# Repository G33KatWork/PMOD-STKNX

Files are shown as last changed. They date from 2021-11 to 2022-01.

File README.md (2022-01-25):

STKNX Pmod
==========

**WARNING**: See [known issues](#known-issues) before ordering boards!

This is a small breakout board for an ST microelectronics [STKNX KNX line transceiver](https://www.st.com/en/interfaces-and-transceivers/stknx.html)

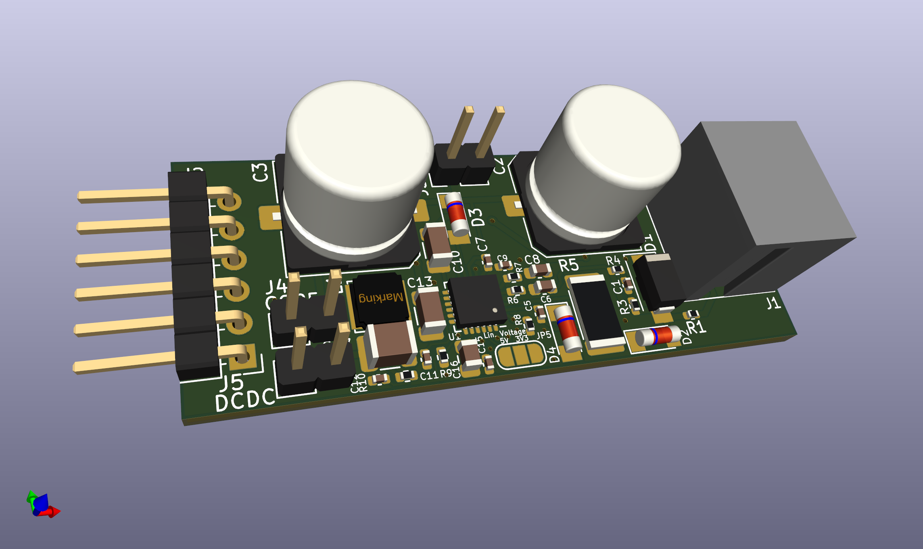
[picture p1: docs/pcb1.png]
PCB Front


Hardware
--------

The board is currently being manufactured and the design has briefly been powered up and tested - it didn't go up in flames... yet. It is very close to the ST reference design of the EVALKITSTKNX development board, just without the microcontroller

The STKNX is not a full KNX MAC. It is only a line transceiver that performs some KNX bus compliant signal conditioning and also delivers power using its voltage regulators from the bus to the device.

There is no real open source software support right now for bit-banging the KNX protocol using this transceiver. It is very useful to perform sniffing tasks on the bus if you are interested in the raw bits that are sent.

Known issues
------------

The polarization of the KNX connector is wrong. It's a pretty dumb mistake, but oh well, it happened.

Possible solutions:

1. Don't care, connect the red wire to the black terminal and vice versa
2. Don't care like in 1) but use the yellow/white WAGO terminal to make sure you remember to swap the polarity
3. Take apart a WAGO terminal by force and swap the black and red terminal
4. Solder the pins on the bottom of the board and plug the WAGO terminal in there.
5. Cut the GND connections on the one pin, cut the bus connection on the other pin and bodge the GND and bus connection to the right pins
6. Fix it in the board design, reorder and rebuild the boards

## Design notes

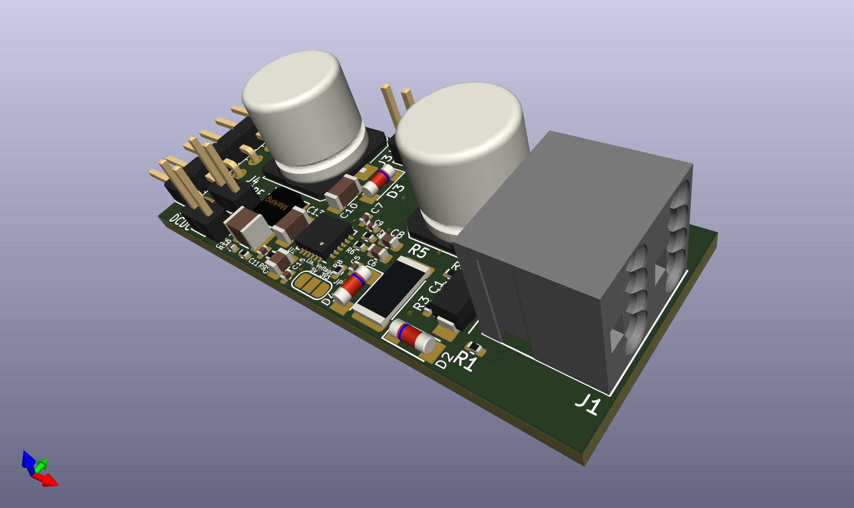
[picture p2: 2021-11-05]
docs/pcb3.png

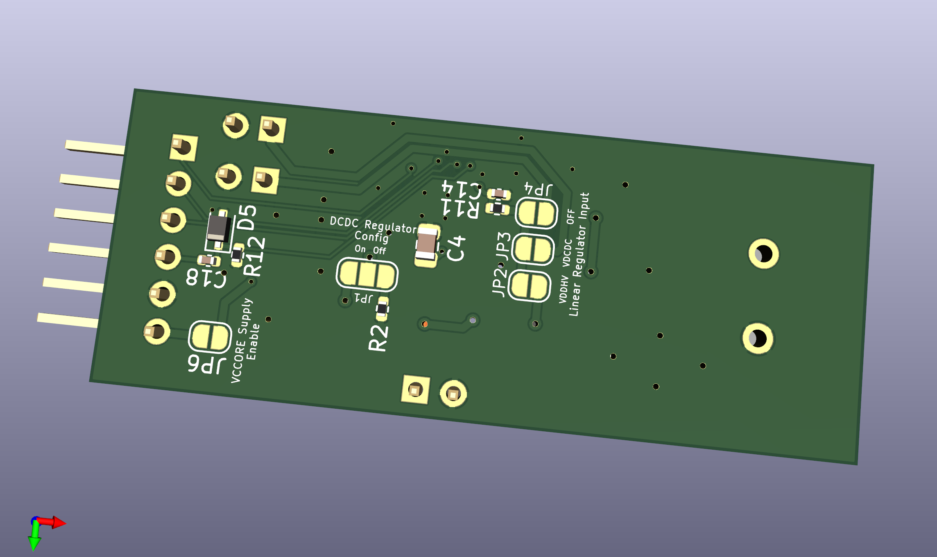
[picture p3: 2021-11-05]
docs/pcb2.png

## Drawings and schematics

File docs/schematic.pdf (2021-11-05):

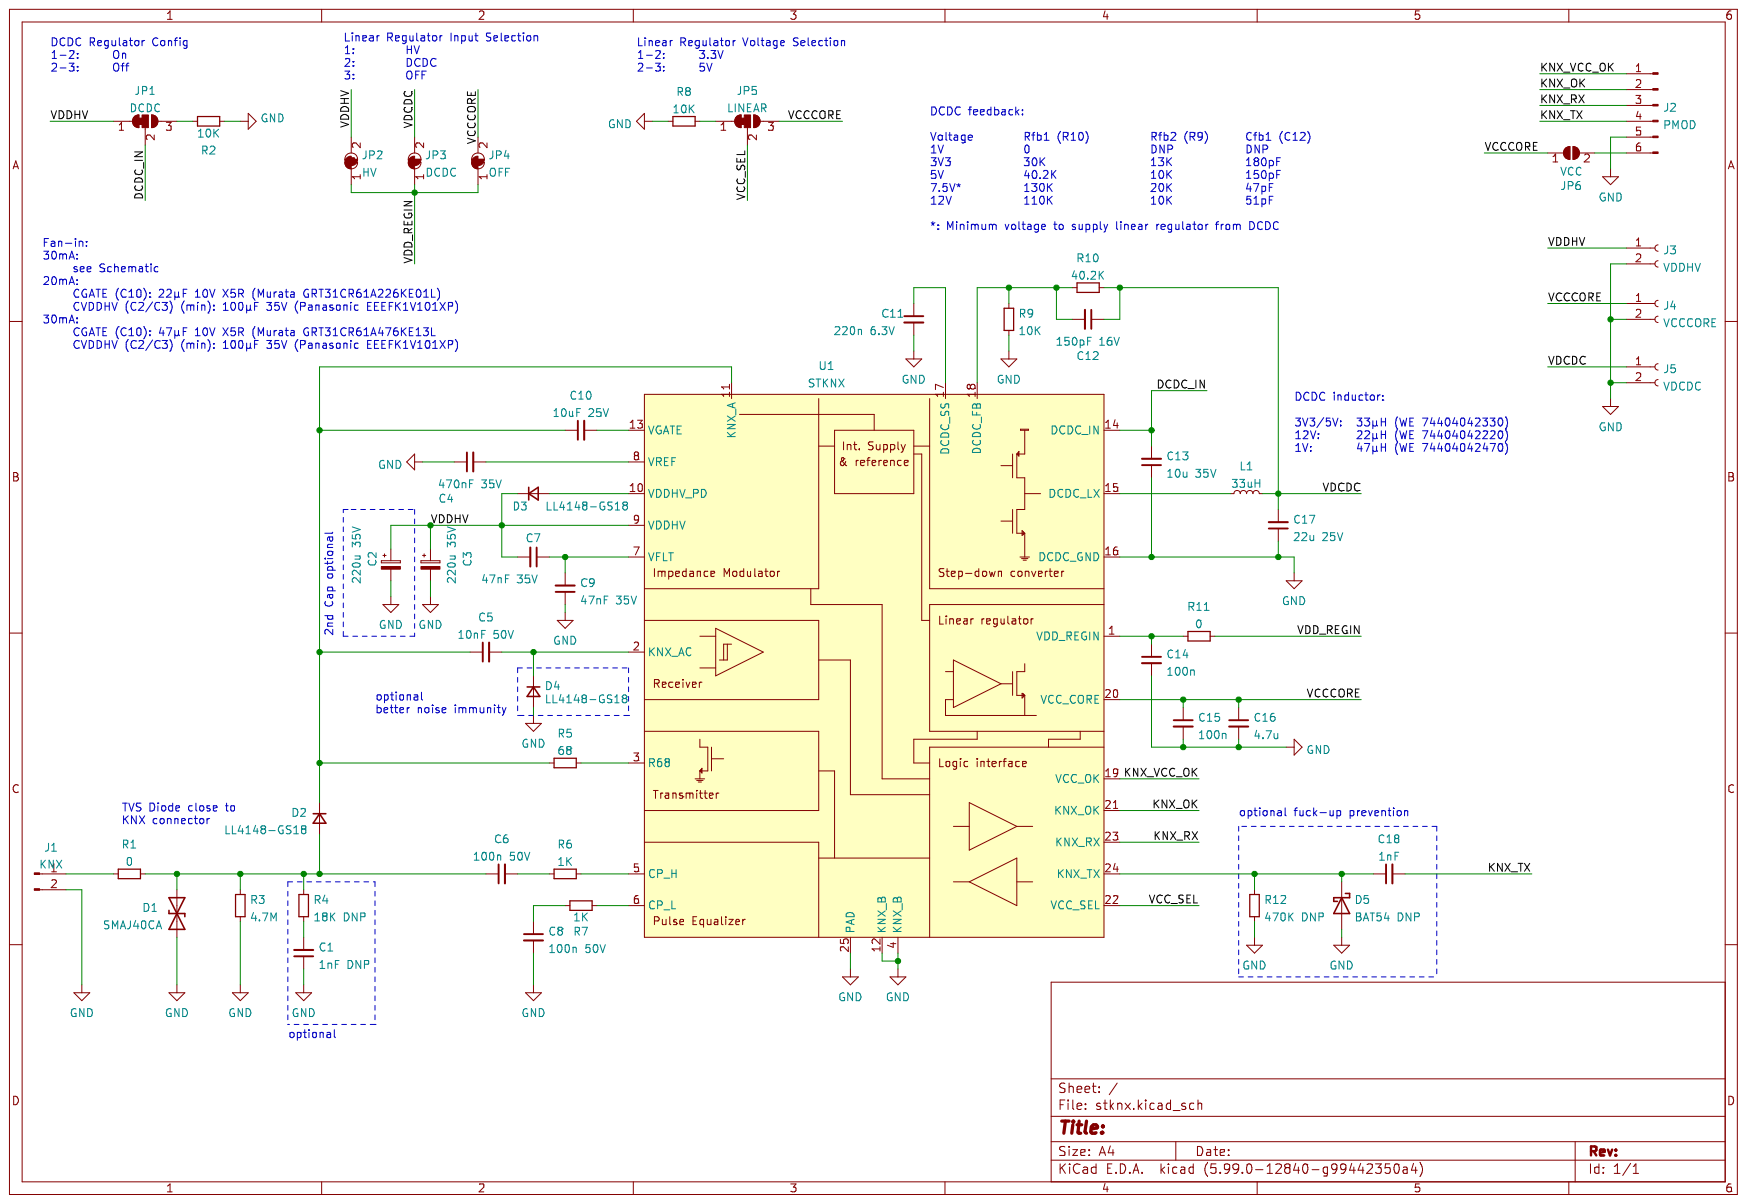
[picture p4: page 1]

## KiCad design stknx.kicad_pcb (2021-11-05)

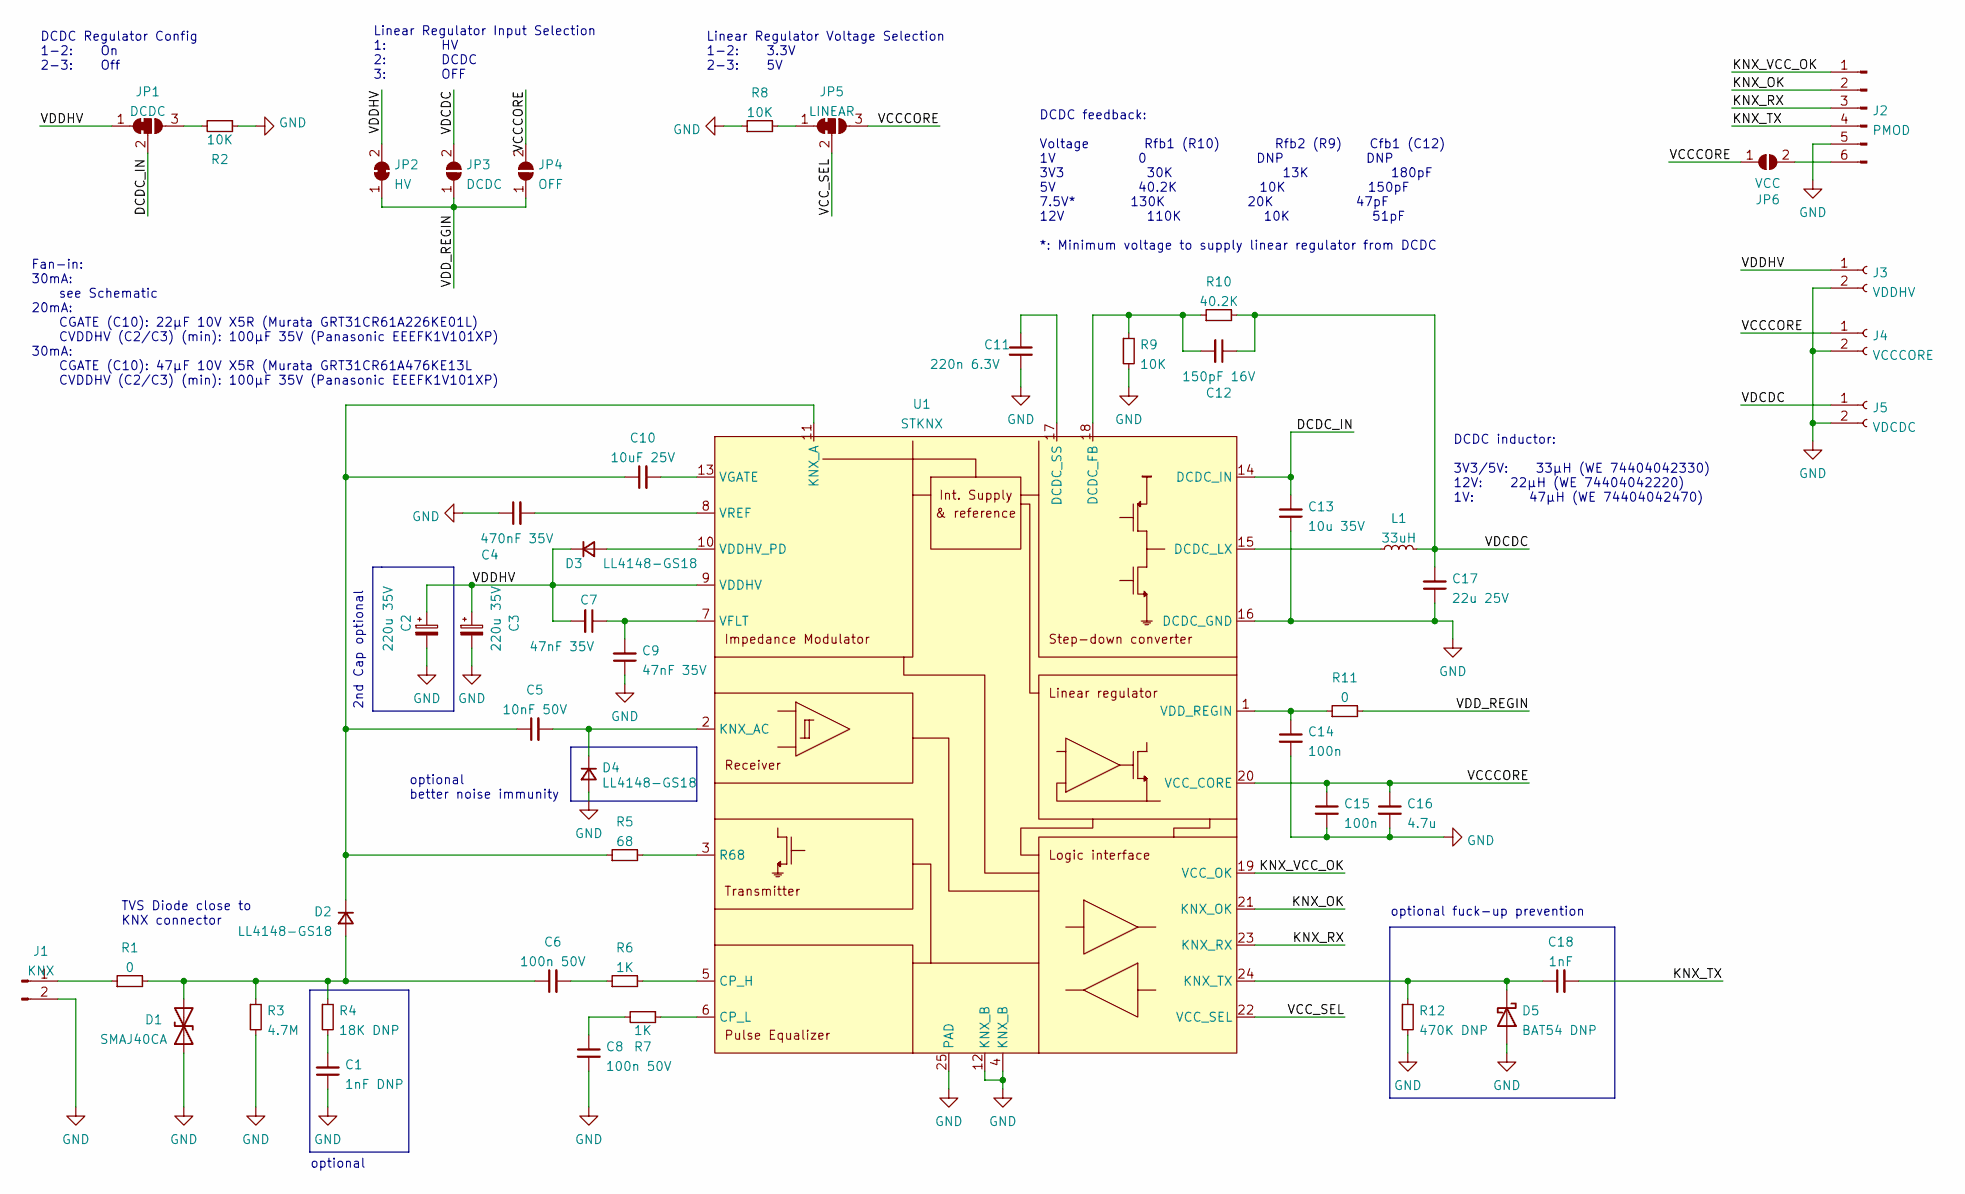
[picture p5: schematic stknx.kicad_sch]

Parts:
C1: 1nF DNP; C_0402_1005Metric; Part Description 1000pF ±10% 50V Ceramic Capacitor X7R 0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
C2, C3: 220u 35V; C_Elec_10x10.2; Part Description 220µF 50V Aluminum Electrolytic Capacit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
C4: 470nF 35V; C_0805_2012Metric; Part Description 0.47µF ±10% 50V Ceramic Capacitor X7R 0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
C5: 10nF 50V; C_0402_1005Metric; Part Description 10000pF ±10% 50V Ceramic Capacitor X7R 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
C6, C8: 100n 50V; C_0603_1608Metric; Part Description 0.1µF ±10% 50V Ceramic Capacitor X7R 06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
C7, C9: 47nF 35V; C_0402_1005Metric; Part Description 0,047µF ±10% 50V Keramikkondensatoren X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
C10: 10uF 25V; C_1206_3216Metric; Part Description 10µF ±10% 25V Ceramic Capacitor X7R 120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
C11: 220n 6.3V; C_0402_1005Metric; Part Description 0.22µF ±10% 10V Ceramic Capacitor X7R 0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
C12: 150pF 16V; C_0402_1005Metric; Part Description 150pF ±10% 16V Ceramic Capacitor X7R 04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
C13: 10u 35V; C_1206_3216Metric; Part Description 10µF ±10% 35V Ceramic Capacitor X5R 120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
C14, C15: 100n; C_0402_1005Metric; Part Description 0.1µF ±10% 25V Ceramic Capacitor X7R 04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
C16: 4.7u; C_0805_2012Metric; Part Description 4.7µF ±10% 6.3V Ceramic Capacitor X7R 0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
C17: 22u 25V; C_1210_3225Metric; Part Description 22µF ±20% 25V Ceramic Capacitor X7R 121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
C18: 1nF; C_0402_1005Metric; Part Description 1000pF ±10% 50V Ceramic Capacitor X7R 0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
D1: SMAJ40CA; D_SMA; Part Description 64.5V Clamp 6.2A Ipp Tvs Diode Surface 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
D2, D3, D4: LL4148-GS18; D_MiniMELF; Part Description Diode Standard 75V 300mA (DC) Surface M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
D5: BAT54 DNP; D_SOD-323F; Part Description Diode Schottky 30V 200mA Surface Mount 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
J1: KNX; WAGO_243-211; Part Description KNX Klemme Stifte, 2x
J2: PMOD; PinHeader_1x06_P2.54mm_Horizontal; Part Description Connector Header Through Hole, Right An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
J3: VDDHV; PinHeader_1x02_P2.54mm_Vertical
J4: VCCCORE; PinHeader_1x02_P2.54mm_Vertical
J5: VDCDC; PinHeader_1x02_P2.54mm_Vertical
JP1: DCDC; SolderJumper-3_P1.3mm_Open_RoundedPad1.0x1.5mm_NumberLabels
JP2: HV; SolderJumper-2_P1.3mm_Open_RoundedPad1.0x1.5mm
JP3: DCDC; SolderJumper-2_P1.3mm_Open_RoundedPad1.0x1.5mm
JP4: OFF; SolderJumper-2_P1.3mm_Open_RoundedPad1.0x1.5mm
JP5: LINEAR; SolderJumper-3_P1.3mm_Open_RoundedPad1.0x1.5mm_NumberLabels
JP6: VCC; SolderJumper-2_P1.3mm_Open_RoundedPad1.0x1.5mm
L1: 33uH; L_WE_LQS_4012; Part Description 33µH Semi-Shielded Wirewound Inductor 6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
R1, R11: 0; R_0402_1005Metric; Part Description 0 Ohms Jumper 0.063W, 1/16W Chip Resist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
R2, R8: 10K; R_0402_1005Metric; Part Description 10 kOhms ±5% 0.063W, 1/16W Chip Resisto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
R3: 4.7M; R_0402_1005Metric; Part Description 4.7 MOhms ±1% 0.063W, 1/16W Chip Resist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
R4: 18K DNP; R_0402_1005Metric; Part Description 18 kOhms ±1% 0.063W, 1/16W Chip Resisto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
R5: 68; R_2512_6332Metric; Part Description 68 Ohms ±1% 1W Chip Resistor 2512 (6432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
R6, R7: 1K; R_0402_1005Metric; Part Description 1 kOhms ±1% 0.063W, 1/16W Chip Resistor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
R9: 10K; R_0402_1005Metric; Part Description 10 kOhms ±0.1% 0.063W, 1/16W Chip Resis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
R10: 40.2K; R_0402_1005Metric; Part Description 40.2 kOhms ±0.1% 0.063W, 1/16W Chip Res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
R12: 470K DNP; R_0402_1005Metric; Part Description 470 kOhms ±1% 0.063W, 1/16W Chip Resist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
U1: STKNX; VQFN-24-1EP_4x4mm_P0.5mm_EP2.45x2.45mm; Part Description 0/1 Transceiver 24-VFQFPN (4x4)

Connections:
/DCDC_IN: C13.2, JP1.2 (C), U1.14 (DCDC_IN)
/KNX_OK: J2.2, U1.21 (KNX_OK)
/KNX_RX: J2.3, U1.23 (KNX_RX)
/KNX_TX: C18.2, J2.4
/KNX_VCC_OK: J2.1, U1.19 (VCC_OK)
/VCCCORE: C15.1, C16.1, J4.1, JP4.2 (B), JP5.3 (B), JP6.1 (A), U1.20 (VCC_CORE)
/VCC_SEL: JP5.2 (C), U1.22 (VCC_SEL)
/VDCDC: C12.1, C17.2, J5.1, JP3.2 (B), L1.2, R10.2
/VDDHV: C2.1, C3.1, C7.2, D3.1 (K), J3.1, JP1.1 (A), JP2.2 (B), U1.9 (VDDHV)
/VDD_REGIN: JP2.1 (A), JP3.1 (A), JP4.1 (A), R11.2
GND: C1.1, C2.2, C3.2, C4.1, C8.2, C9.1, C11.2, C13.1, C14.2, C15.2, C16.2, C17.1, D1.1 (A1), D4.2 (A), D5.2 (A), J1.2, J2.5, J3.2, J4.2, J5.2, R2.1, R3.2, R8.1, R9.2, R12.2, U1.4 (KNX_B), U1.12 (KNX_B), U1.16 (DCDC_GND), U1.25 (PAD)
unnamed: C1.2, R4.2
unnamed: C4.2, U1.8 (VREF)
unnamed: C5.2, D4.1 (K), U1.2 (KNX_AC)
unnamed: C6.1, D1.2 (A2), D2.2 (A), R1.2, R3.1, R4.1
unnamed: C6.2, R6.1
unnamed: C7.1, C9.2, U1.7 (VFLT)
unnamed: C8.1, R7.2
unnamed: C5.1, C10.1, D2.1 (K), R5.1, U1.11 (KNX_A)
unnamed: C10.2, U1.13 (VGATE)
unnamed: C11.1, U1.17 (DCDC_SS)
unnamed: C12.2, R9.1, R10.1, U1.18 (DCDC_FB)
unnamed: C14.1, R11.1, U1.1 (VDD_REGIN)
unnamed: C18.1, D5.1 (K), R12.1, U1.24 (KNX_TX)
unnamed: D3.2 (A), U1.10 (VDDHV_PD)
unnamed: J1.1, R1.1
unnamed: J2.6, JP6.2 (B)
unnamed: JP1.3 (B), R2.2
unnamed: JP5.1 (A), R8.2
unnamed: L1.1, U1.15 (DCDC_LX)
unnamed: R5.2, U1.3 (R68)
unnamed: R6.2, U1.5 (CP_H)
unnamed: R7.1, U1.6 (CP_L)

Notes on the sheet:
Fan-in: 30mA: see Schematic 20mA: CGATE (C10): 22µF 10V X5R (Murata GRT31CR61A226KE01L) CVDDHV (C2/C3) (min): 100µF 35V (Panasonic EEEFK1V101XP) 30mA: CGATE (C10): 47µF 10V X5R (Murata GRT31CR61A476KE13L CVDDHV (C2/C3) (min): 100µF 35V (Panasonic EEEFK1V101XP)
DCDC Regulator Config 1-2: On 2-3: Off
TVS Diode close to KNX connector
optional
2nd Cap optional
Linear Regulator Input Selection 1: HV 2: DCDC 3: OFF
optional better noise immunity
Linear Regulator Voltage Selection 1-2: 3.3V 2-3: 5V
DCDC feedback: Voltage Rfb1 (R10) Rfb2 (R9) Cfb1 (C12) 1V 0 DNP DNP 3V3 30K 13K 180pF 5V 40.2K 10K 150pF 7.5V* 130K 20K 47pF 12V 110K 10K 51pF *: Minimum voltage to supply linear regulator from DCDC
optional fuck-up prevention
DCDC inductor: 3V3/5V: 33µH (WE 74404042330) 12V: 22µH (WE 74404042220) 1V: 47µH (WE 74404042470)

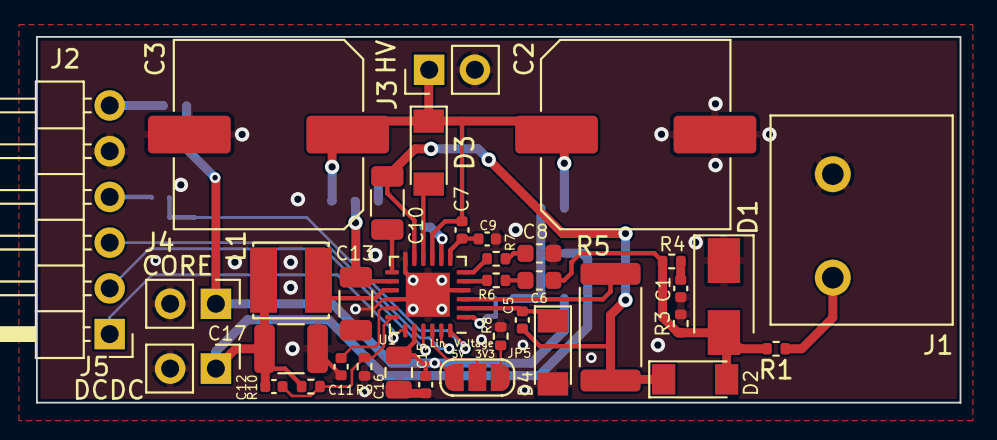
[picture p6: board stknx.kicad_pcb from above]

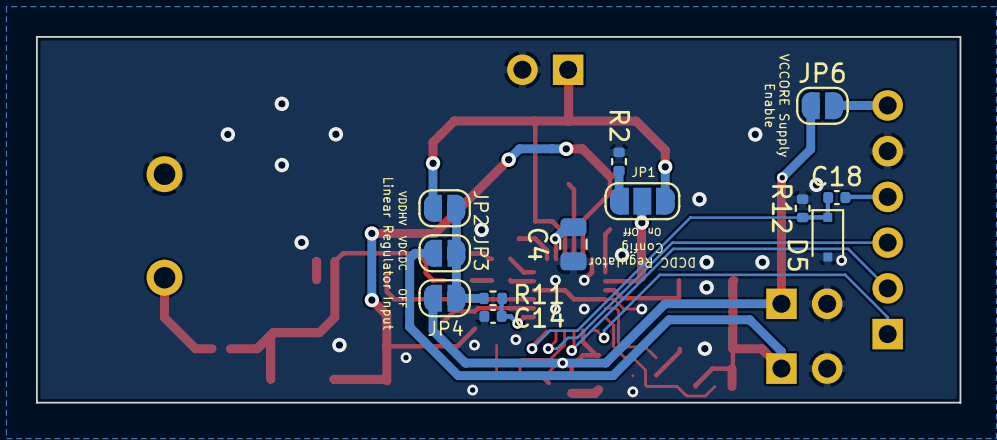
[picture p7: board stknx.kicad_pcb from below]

Board: 2 copper layers, 51.3 x 20.3 mm, 48 parts (12 on the bottom side), 33 nets.

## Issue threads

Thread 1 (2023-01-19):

software implement

BGuiGui, 2023-01-19:
Hello,
I'm interested by this project.
As you write, STKNX is not a full KNX MAC. It is only a line transceiver.
Do you have a software project to Interface shis transceiver with a Knox stack implementation?

G33KatWork, 2023-01-19:
Hi BGuiGui,

unfortunately not. There is an open source KNX stack available at https://github.com/thelsing/knx, but this only implements everything above the link layer, so the transceiver is useless with it. So far I only used the board to sniff bus traffic.

I always wanted to try and use the PIOs in the Raspberry Pi RP2040 to implement the KNX Data Link Layer, but I haven't found the time so far. Receiving is relatively easy, because in the end KNX is just a serial port with 9600 baud in an 8e1 config. If you use this transceiver here, you can just hook it up to a UART or implement one in a PIO state machine and you can receive symbols. Transmitting is a bit more complicated as you need to watch the receive line while transmitting and check whether the data that shows up on the bus is actually what you transmitted. If not, you caused a collision and you need to stop transmitting and retry at a later time when the bus is free again. I don't know yet how to implement this with the PIOs, but I also haven't tried yet.

Maybe this helps if you might want to give it a try.

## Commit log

2021-09-17 Initial import
    [stknx.kicad_pcb, stknx.kicad_sch]
2021-09-17 Make R5 not go up in flames once we transmit the first bit
    [stknx.kicad_sch]
2021-09-17 Rotate D4
    [stknx.kicad_sch]
2021-09-17 Inductor footprint
    [stknx.kicad_sch]
2021-09-18 Rough component placement
    [stknx.kicad_pcb, stknx.kicad_sch]
2021-09-20 First attempts at routing
    [stknx.kicad_pcb, stknx.kicad_sch]
2021-09-20 Minor fixes
    [stknx.kicad_pcb]
2021-09-20 A few DRC fixes
    [stknx.kicad_pcb]
2021-09-20 improve GND connectivity a bit
    [stknx.kicad_pcb]
2021-09-20 make power trace width more consistent
    [stknx.kicad_pcb]
2021-09-20 reroute with jlc specs
    [stknx.kicad_pcb]
2021-09-20 via size fasching and some GND optimization
    [stknx.kicad_pcb]
2021-09-21 fix U1 pin 4 connectivity
    [stknx.kicad_pcb]
2021-09-25 Remove default-jumpers and replace them with open jumpers to avoid the need to scratch around on that beatiful PCB
    [stknx.kicad_pcb, stknx.kicad_sch]
2021-09-25 Silkscreen for JP5
    [stknx.kicad_pcb]
2021-11-05 Add Gerbers
    [stknx-B_Cu.gbl, stknx-B_Mask.gbs, stknx-B_Paste.gbp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]
2021-11-05 Add schematic and PCB renderings for posing on Twitter
